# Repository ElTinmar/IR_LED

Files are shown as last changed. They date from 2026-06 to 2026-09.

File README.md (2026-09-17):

# IR_LED

This is an open-source infra-red illumnination solution (LED panel and driver) for machine vision.
An arduino nano every sits at the core of the driver board, and allows remote control from a PC through serial communication

The main features are: 

- infra-red LED panel, with 3 separately addressable concentric rings  
- manual or remote control of the brightness for the 3 channels
- LED driver can be strobed with the open-collector trigger output of a machine vision camera,
which significantly reduces heat output
- the temperature of the LED panel is measured in real time and can by controlled with a fan. 
The fan PWM can be set manually or via a software PID controller on the arduino

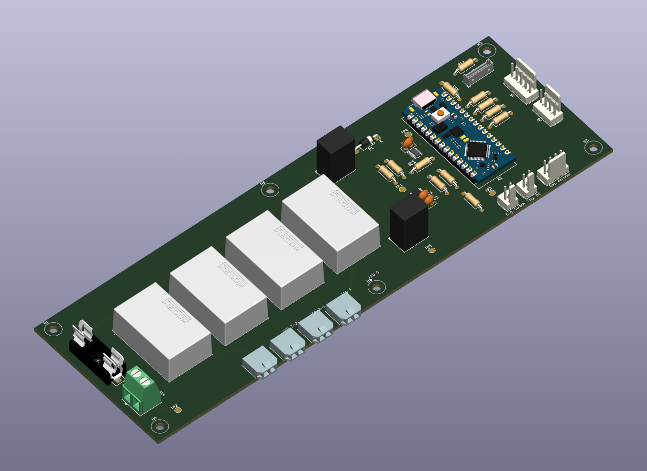
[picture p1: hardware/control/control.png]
Control Board Schematic


## hardware

PCB design files (Kicad v10)

## firmware

Arduino code (Arduino Nano Every)
 
## software

Python driver and GUI on the PC side

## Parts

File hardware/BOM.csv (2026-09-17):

num boards: | 2
board | Id | Designator | Footprint | Quantity (per board) | Safety margin (+ x%) | Quantity (total) | Designation | Supplier | Ref | Unit price | Price total | Link
rotary_encoder | 1 | H1, H2 | MountingHole_2.2mm_M2 | 2 | 0 | 4 | MountingHole
rotary_encoder | 2 | J1 | Molex_KK-254_AE-6410-04A_1x04_P2.54mm_Vertical | 1 | 100 | 4 | Conn_01x04_Pin | Mouser | 538-22-29-2041 | 0.579 | 2.316 | https://www.mouser.de/en/ProductDetail/Molex/22-29-2041
rotary_encoder | 3 | SW1 | RotaryEncoder_Alps_EC11E-Switch_Vertical_H20mm | 1 | 0 | 2 | RotaryEncoder_Switch | Mouser | 688-EC11E183440C | 6.03 | 12.06 | https://www.mouser.de/en/ProductDetail/Alps-Alpine/EC11E183440C
status_LED | 1 | D1, D2, D3, D4 | LED_D5.0mm | 4 | 0 | 8 | LED | Mouser | 941-C503BABNCW0X0342 | 0.127 | 1.016 | https://www.mouser.de/en/ProductDetail/Cree-LED/C503B-ABN-CW0X0342
status_LED | 2 | H1, H2 | MountingHole_2.2mm_M2 | 2 | 0 | 4 | MountingHole
status_LED | 3 | J1 | Molex_KK-254_AE-6410-05A_1x05_P2.54mm_Vertical | 1 | 0 | 2 | Conn_01x05_Pin | Mouser | 538-22-27-2051 | 0.36 | 0.72 | https://www.mouser.de/en/ProductDetail/Molex/22-27-2051
control | 1 | A1 | Arduino_Nano | 1 | 0 | 2 | Arduino_Nano_Every | Mouser | 782-ABX00033 | 12.81 | 25.62 | https://www.mouser.de/en/ProductDetail/Arduino/ABX00033
control | 2 | C1, C4 | C_Disc_D5.0mm_W2.5mm_P2.50mm | 2 | 0 | 4 | 0.1uF | Mouser | 75-1C10X7R104K100B | 0.198 | 0.792 | https://www.mouser.de/en/ProductDetail/Vishay-Sprague/1C10X7R104K100B
control | 3 | C2 | C_Disc_D5.0mm_W2.5mm_P2.50mm | 1 | 0 | 2 | 10uF | Mouser | RCER71E106K3DBH03A | 0.476 | 0.952 | https://www.mouser.de/en/ProductDetail/Murata-Electronics/RCER71E106K3DBH03A
control | 4 | D1 | D_DO-41_SOD81_P10.16mm_Horizontal | 1 | 0 | 2 | 1N5817 | Mouser | 625-1N5817-E3/73 | 0.132 | 0.264 | https://www.mouser.de/en/ProductDetail/Vishay-Semiconductors/1N5817-E3-73
control | 5 | F1 | FUSE_646_1_LTF | 1 | 0 | 2 | 64600001003 | Mouser | 576-64600001003 | 0.903 | 1.806 | https://www.mouser.de/en/ProductDetail/Littelfuse/64600001003
control | 6 | H1, H2, H3, H4, H5, H6 | MountingHole_3.2mm_M3 | 6 | 0 | 12 | MountingHole
control | 7 | IC1 | SOP50P326X110-16N | 1 | 100 | 4 | TMUX4053DYYR | Mouser | 595-TMUX4053DYYR | 0.356 | 1.424 | https://www.mouser.de/en/ProductDetail/Texas-Instruments/TMUX4053DYYR
control | 8 | J1, J2, J3, J4 | Molex_Micro-Fit_3.0_43650-0200_1x02_P3.00mm_Horizontal | 4 | 100 | 16 | Conn_01x02_Pin | Mouser | 538-43650-0200 | 0.785 | 12.56 | https://www.mouser.de/en/ProductDetail/Molex/43650-0200
control | 9 | J5 | Molex_KK-254_AE-6410-05A_1x05_P2.54mm_Vertical | 1 | 100 | 4 | Conn_01x05_Pin | Mouser | 538-22-27-2051 | 0.36 | 1.44 | https://www.mouser.de/en/ProductDetail/Molex/22-27-2051
control | 10 | J6, J11 | Molex_KK-254_AE-6410-04A_1x04_P2.54mm_Vertical | 2 | 100 | 8 | Conn_01x04_Pin | Mouser | 538-22-29-2041 | 0.579 | 4.632 | https://www.mouser.de/en/ProductDetail/Molex/22-29-2041
control | 11 | J7 | Molex_PicoBlade_53047-0810_1x08_P1.25mm_Vertical | 1 | 100 | 4 | Conn_01x08_Pin | Mouser | 538-53047-0810 | 0.361 | 1.444 | https://www.mouser.de/en/ProductDetail/Molex/53047-0810
control | 12 | J8, J12 | Molex_KK-254_AE-6410-02A_1x02_P2.54mm_Vertical | 2 | 100 | 8 | Conn_01x02_Pin | Mouser | 538-22-29-2021 | 0.376 | 3.008 | https://www.mouser.de/en/ProductDetail/Molex/22-29-2021
control | 13 | J9 | TerminalBlock_Phoenix_MKDS-1,5-2-5.08_1x02_P5.08mm_Horizontal | 1 | 0 | 2 | Screw_Terminal_01x02 | Mouser | 651-1985904 | 1.01 | 2.02 | https://www.mouser.de/en/ProductDetail/Phoenix-Contact/1985904
control | 14 | PS1, PS2, PS3, PS4 | CONV_CRED-48-1.05 | 4 | 0 | 8 | RCDE-48-1.05 | Mouser | 919-RCDE-48-1.05 | 7.43 | 59.44 | https://www.mouser.de/en/ProductDetail/RECOM-Power/RCDE-48-1.05
control | 15 | R1, R2, R3, R10, R11, R12 | R_Axial_DIN0207_L6.3mm_D2.5mm_P10.16mm_Horizontal | 6 | 0 | 12 | 10k
control | 16 | R4, R5 | R_Axial_DIN0207_L6.3mm_D2.5mm_P10.16mm_Horizontal | 2 | 0 | 4 | 4.7k
control | 17 | R6, R7, R8, R9 | R_Axial_DIN0207_L6.3mm_D2.5mm_P10.16mm_Horizontal | 4 | 0 | 8 | 220
control | 18 | TP1, TP2, TP3, TP4, TP5, TP6 | TestPoint_Pad_D2.0mm | 6 | 0 | 12 | TestPoint
control | 19 | U2 | MSOP-10_3x3mm_P0.5mm | 1 | 0 | 2 | MCP4728 | Mouser | 579-MCP4728-E/UN | 2.15 | 4.3 | https://www.mouser.de/en/ProductDetail/Microchip-Technology/MCP4728-E-UN
control | 20 | U4 | Converter_DCDC_RECOM_R-78HB-0.5_THT | 1 | 0 | 2 | R-78HB12-0.5 | Mouser | 919-R-78HB12-0.5 | 14.67 | 29.34 | https://www.mouser.de/en/ProductDetail/RECOM-Power/R-78HB12-0.5
control | 21 | U5 | Converter_DCDC_RECOM_R-78HB-0.5_THT | 1 | 0 | 2 | R-78HB5.0-0.5 | Mouser | 919-R-78HB5.0-0.5 | 13.67 | 27.34 | https://www.mouser.de/en/ProductDetail/RECOM-Power/R-78HB5.0-0.5
LED_panel | 1 | C1 | C_0805_2012Metric | 1 | 0 | 2 | 0.1uF | Mouser | 81-GCJ21BR71E104KA1L | 0.361 | 0.722 | https://www.mouser.de/en/ProductDetail/Murata-Electronics/GCJ21BR71E104KA01L
LED_panel | 2 | H1, H2, H3, H4, H5, H6 | MountingHole_3.2mm_M3 | 6 | 0 | 12 | MountingHole
LED_panel | 3 | IC1 | SOT65P210X110-6N | 1 | 100 | 4 | TMP126NDCKR | Mouser | 595-TMP126NDCKR | 1.12 | 4.48 | https://www.mouser.de/en/ProductDetail/Texas-Instruments/TMP126NDCKR
LED_panel | 4 | J0, J1, J2-1, J2-2 | Molex_Micro-Fit_3.0_43650-0224_1x02-1MP_P3.00mm_Vertical | 4 | 100 | 16 | Conn_01x02_Pin | Mouser | 538-43650-0224 | 2.05 | 32.8 | https://www.mouser.de/en/ProductDetail/Molex/43650-0224
LED_panel | 5 | J2 | Molex_PicoBlade_53261-0871_1x08-1MP_P1.25mm_Horizontal | 1 | 100 | 4 | Conn_01x08_Pin | Mouser | 538-53261-0871 | 0.869 | 3.476 | https://www.mouser.de/en/ProductDetail/Molex/53261-0871
LED_panel | 6 | LED1, LED2, LED3, LED4, LED5, LED6, LED7, LED8, LED9, LED10, LED11, LED12, LED13, LED14, LED15, LED16, LED17, LED18, LED19, LED20, LED21, LED22, LED23, LED24, LED25, LED26, LED27, LED28, LED29, LED30, LED31, LED32, LED33, LED34, LED35, LED36 | SFH4725ASA01 | 36 | 25 | 90 | SFH_4725AS_A01 | Mouser | 720-SFH4725ASAA0273 | 2.47 | 222.3 | https://www.mouser.de/en/ProductDetail/ams-OSRAM/SFH-4725AS-A01
 |  |  |  |  |  | 0
cables |  |  |  |  |  | 0
Control : LED_panel | 1 |  |  | 1 | 0 | 2 | PicoBlade 8 positions female/female | Mouser | 538-15134-0801 | 5.99 | 11.98 | https://www.mouser.de/en/ProductDetail/Molex/15134-0801
Control : LED_panel | 2 |  |  | 4 | 0 | 8 | MicroFit3.0 2 positions female/female | Mouser | 538-214750-1021 | 2.19 | 17.52 | https://www.mouser.de/en/ProductDetail/Molex/214750-1021
Control : rotary_encoder | 1 |  |  | 1 | 0 | 2 | KK 4 positions female/female | Mouser | 538-217796-1042 | 3.08 | 6.16 | https://www.mouser.de/en/ProductDetail/Molex/217796-1042
Control : switch | 1 |  |  | 1 | 0 | 2 | KK 2 positions female/pigtail | Mouser | 538-217797-1023 | 1.94 | 3.88 | https://www.mouser.de/en/ProductDetail/Molex/217797-1023
Control : camera | 1 |  |  | 1 | 0 | 2 | KK 2 positions female/pigtail | Mouser | 538-217797-1023 | 1.94 | 3.88 | https://www.mouser.de/en/ProductDetail/Molex/217797-1023
Control : status_LED | 1 |  |  | 1 | 0 | 2 | KK 5 positions female/female | Mouser | 538-217796-1052 | 2.67 | 5.34 | https://www.mouser.de/en/ProductDetail/Molex/217796-1052
other components
switch | 1 |  |  | 1 | 0 | 2 | SPST cam trigger switch PM | Mouser | 633-MN11S2A1W01 | 5.19 | 10.38 | https://www.mouser.de/en/ProductDetail/NKK-Switches/MN11S2A1W01
PSU | 2 |  |  | 1 | 0 | 2 | MeanWell | Digikey | 1866-2274-ND | 90.7 | 181.4 | https://www.digikey.de/de/products/detail/mean-well-usa-inc/HEP-240-48A/7703829
extra
solder paste |  |  |  |  |  | 1 | Lead free, Sn96.5/Ag03/Cu0.5 | Mouser | 910-SMD291SNL10T5 | 32.01 | 32.01 | https://www.mouser.de/en/ProductDetail/Chip-Quik/SMD291SNL10T5
fuses |  |  |  |  |  | 10 | MeanWell HEP-240-48 | Mouser | 576-0235006.MXP | 0.466 | 4.66 | https://www.mouser.de/en/ProductDetail/Littelfuse/0235006.MXP

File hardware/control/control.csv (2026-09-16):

Id | Designator | Footprint | Quantity | Designation | Supplier and ref
1 | A1 | Arduino_Nano | 1 | Arduino_Nano_Every
2 | C1, C4 | C_Disc_D5.0mm_W2.5mm_P2.50mm | 2 | 0.1uF
3 | C2 | C_Disc_D5.0mm_W2.5mm_P2.50mm | 1 | 10uF
4 | D1 | D_DO-41_SOD81_P10.16mm_Horizontal | 1 | 1N5817
5 | F1 | FUSE_646_1_LTF | 1 | 64600001003
6 | H1, H2, H3, H4, H5, H6 | MountingHole_3.2mm_M3 | 6 | MountingHole
7 | IC1 | SOP50P326X110-16N | 1 | TMUX4053DYYR
8 | J1, J2, J3, J4 | Molex_Micro-Fit_3.0_43650-0200_1x02_P3.00mm_Horizontal | 4 | Conn_01x02_Pin
9 | J5 | Molex_KK-254_AE-6410-05A_1x05_P2.54mm_Vertical | 1 | Conn_01x05_Pin
10 | J6, J11 | Molex_KK-254_AE-6410-04A_1x04_P2.54mm_Vertical | 2 | Conn_01x04_Pin
11 | J7 | Molex_PicoBlade_53047-0810_1x08_P1.25mm_Vertical | 1 | Conn_01x08_Pin
12 | J8, J12 | Molex_KK-254_AE-6410-02A_1x02_P2.54mm_Vertical | 2 | Camera Isolated triggers (open collector)
13 | J9 | TerminalBlock_Phoenix_MKDS-1,5-2-5.08_1x02_P5.08mm_Horizontal | 1 | Screw_Terminal_01x02
14 | PS1, PS2, PS3, PS4 | CONV_RCDE-48-1.05 | 4 | RCDE-48-1.05
15 | R1, R2, R3, R10, R11, R12 | R_Axial_DIN0207_L6.3mm_D2.5mm_P10.16mm_Horizontal | 6 | 10k
16 | R4, R5 | R_Axial_DIN0207_L6.3mm_D2.5mm_P10.16mm_Horizontal | 2 | 4.7k
17 | R6, R7, R8, R9 | R_Axial_DIN0207_L6.3mm_D2.5mm_P10.16mm_Horizontal | 4 | 220
18 | TP1, TP2, TP3, TP4, TP5, TP6 | TestPoint_Pad_D2.0mm | 6 | TestPoint
19 | U2 | MSOP-10_3x3mm_P0.5mm | 1 | MCP4728
20 | U4 | Converter_DCDC_RECOM_R-78HB-0.5_THT | 1 | R-78HB12-0.5
21 | U5 | Converter_DCDC_RECOM_R-78HB-0.5_THT | 1 | R-78HB5.0-0.5

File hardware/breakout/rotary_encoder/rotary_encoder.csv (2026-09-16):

Id | Designator | Footprint | Quantity | Designation | Supplier and ref
1 | H1, H2 | MountingHole_2.2mm_M2 | 2 | MountingHole
2 | J1 | Molex_KK-254_AE-6410-04A_1x04_P2.54mm_Vertical | 1 | Conn_01x04_Pin
3 | SW1 | RotaryEncoder_Alps_EC11E-Switch_Vertical_H20mm | 1 | RotaryEncoder_Switch

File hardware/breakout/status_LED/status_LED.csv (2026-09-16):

Id | Designator | Footprint | Quantity | Designation | Supplier and ref
1 | D1, D2, D3, D4 | LED_D5.0mm | 4 | LED
2 | H1, H2 | MountingHole_2.2mm_M2 | 2 | MountingHole
3 | J1 | Molex_KK-254_AE-6410-05A_1x05_P2.54mm_Vertical | 1 | Conn_01x05_Pin

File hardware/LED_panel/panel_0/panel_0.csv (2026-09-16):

Id | Designator | Footprint | Quantity | Designation | Supplier and ref
1 | C1 | C_0805_2012Metric | 1 | 0.1uF
2 | H1, H2, H3, H4, H5, H6 | MountingHole_3.2mm_M3 | 6 | MountingHole
3 | IC1 | SOT65P210X110-6N | 1 | TMP126NDCKR
4 | J0, J1, J2-1, J2-2 | Molex_Micro-Fit_3.0_43650-0224_1x02-1MP_P3.00mm_Vertical | 4 | Conn_01x02_Pin
5 | J2 | Molex_PicoBlade_53261-0871_1x08-1MP_P1.25mm_Horizontal | 1 | Conn_01x08_Pin
6 | LED1, LED2, LED3, LED4, LED5, LED6, LED7, LED8, LED9, LED10, LED11, LED12, LED13, LED14, LED15, LED16, LED17, LED18, LED19, LED20, LED21, LED22, LED23, LED24, LED25, LED26, LED27, LED28, LED29, LED30, LED31, LED32, LED33, LED34, LED35, LED36 | SFH4725ASA01 | 36 | SFH_4725AS_A01

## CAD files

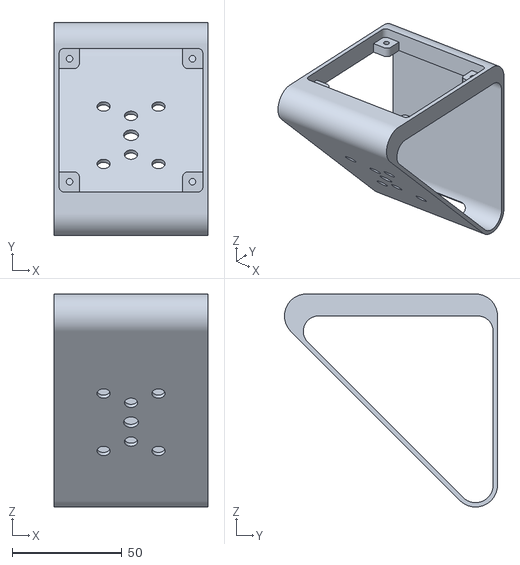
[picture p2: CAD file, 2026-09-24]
hardware/breakout/breakout-base.stl
70.0 x 97.0 x 97.0

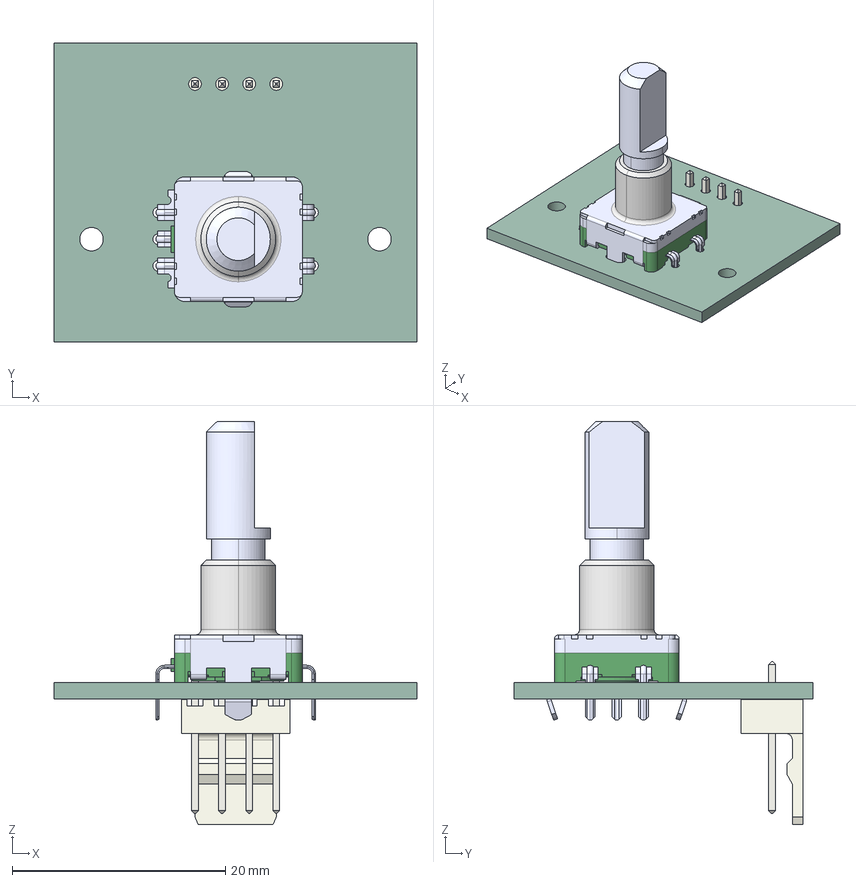
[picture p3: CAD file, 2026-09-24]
hardware/breakout/rotary_encoder/rotary_encoder.step
34.0 x 28.0 x 37.8 mm
EC11E183440C
Molex_AE_6410_04A
rotary_encoder-unsaved-export-sQqqTO_PCB

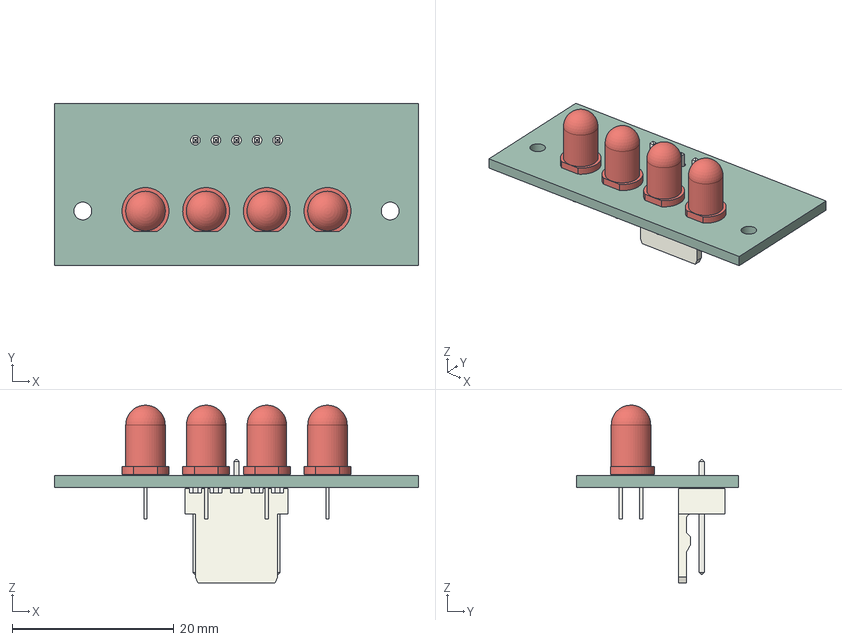
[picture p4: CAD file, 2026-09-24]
hardware/breakout/status_LED/status_LED.step
45.0 x 20.0 x 22.0 mm
LED_D5.0mm x 4
Molex_AE_6410_05A
status_LED-unsaved-export-cohGWM_PCB

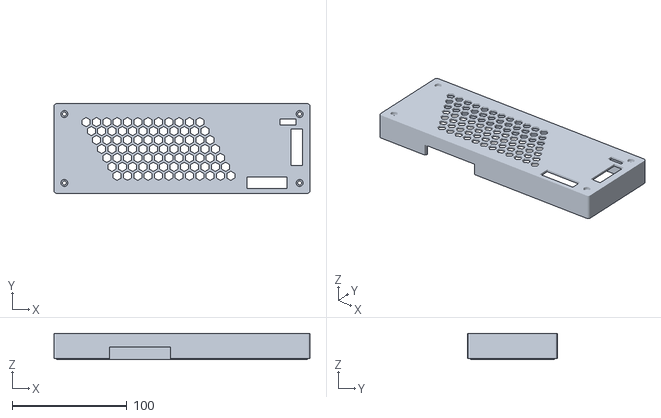
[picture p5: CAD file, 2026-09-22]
hardware/control/control-lid.stl
223.0 x 78.0 x 23.0

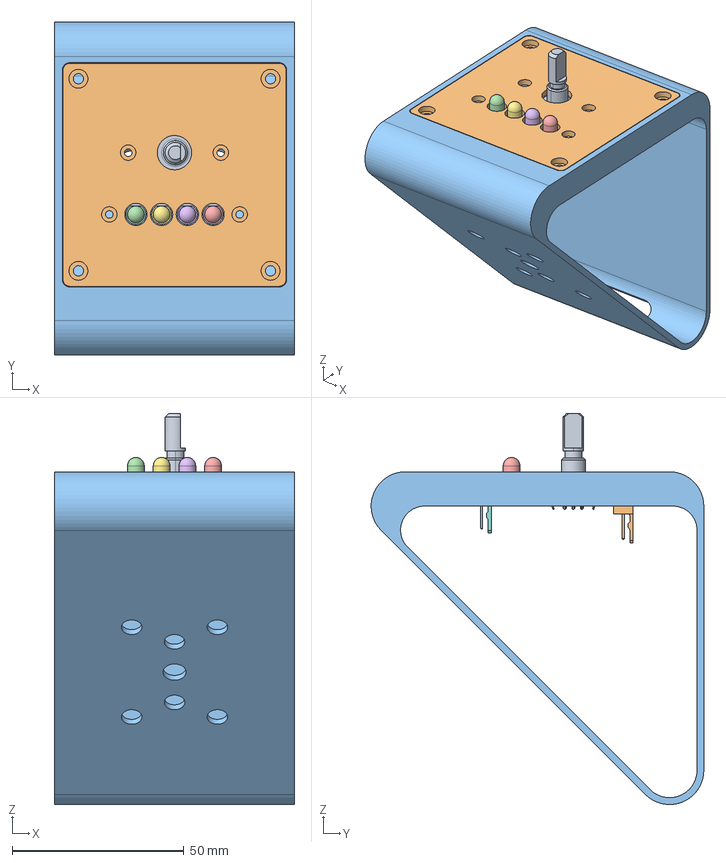
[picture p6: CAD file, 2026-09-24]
hardware/breakout/breakout.FCStd
70.0 x 97.0 x 114.0 mm
EC11E183440C
Molex_AE_6410_04A
rotary_encoder-unsaved-export-sQqqTO_PCB
LED_D5.0mm
LED_D5.0mm002
LED_D5.0mm004
LED_D5.0mm006
Molex_AE_6410_05A
status_LED-unsaved-export-cohGWM_PCB
panel
base

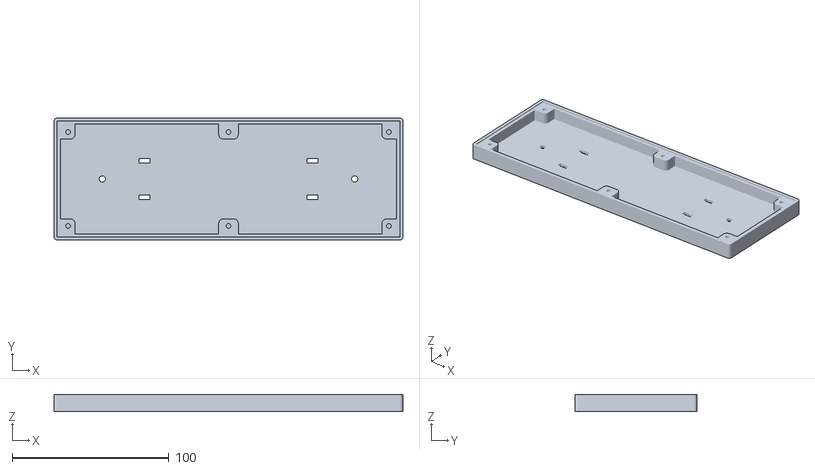
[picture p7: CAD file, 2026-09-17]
hardware/control/control-base.stl
223.0 x 78.0 x 11.0

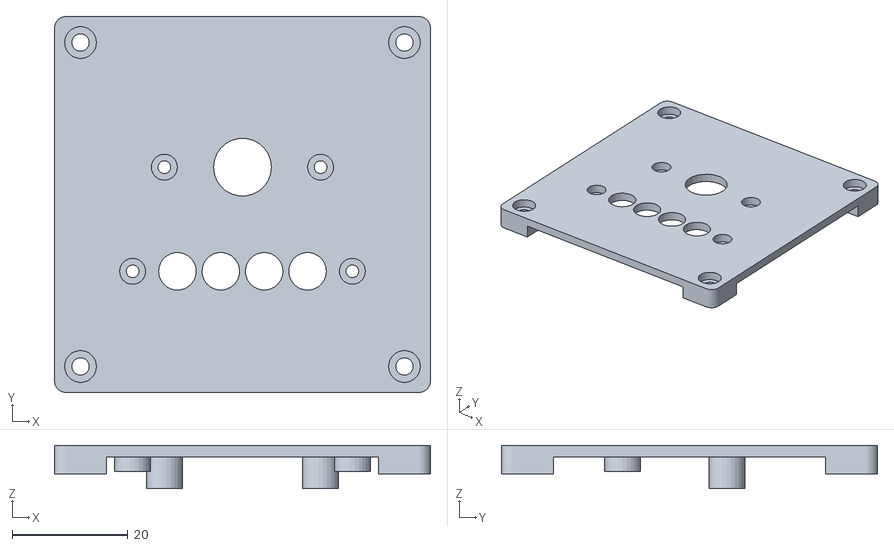
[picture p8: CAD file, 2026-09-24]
hardware/breakout/breakout-panel.stl
65.0 x 65.0 x 7.50

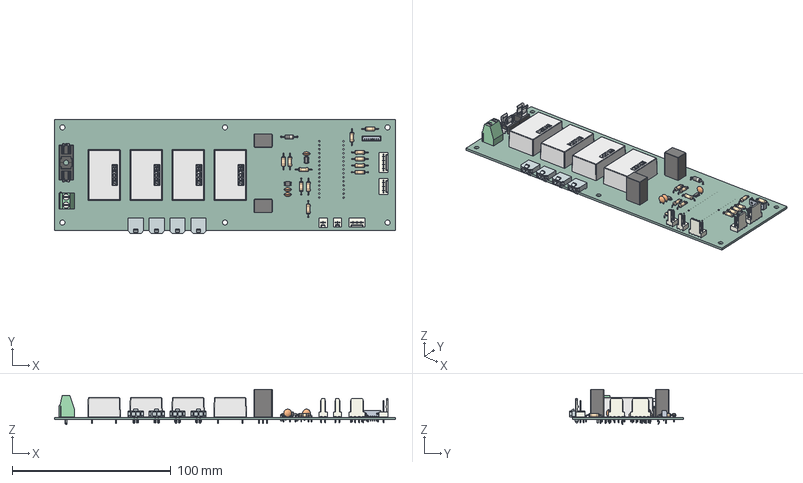
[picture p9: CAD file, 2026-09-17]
hardware/control/control.step
215.0 x 71.9 x 22.3 mm
R_Axial_DIN0207_L63mm_D25mm_P1016mm_Horizontal x 12
436500200wbm000_01 x 4
RCDE-48_pinning x 8
RCDE-48_baseplate x 8
RCDE-48_case x 8
Molex_AE_6410_05A
Molex_AE_6410_02A x 2
Converter_DCDC_RECOM_R-78HB-0.5_THT x 2
BODY-TSSOP x 2
LEAD-TSSOP x 32
C_Disc_D50mm_W25mm_P250mm x 3
MSOP-10_3x3mm_P0.5mm
Molex_AE_6410_04A x 2
T6982
T688800
T6982_MIR1
T688800_MIR1
TerminalBlock_Phoenix_MKDS-1,5-2-5.08_1x02_P5.08mm_Horizontal
D_DO-41_SOD81_P10.16mm_Horizontal
control-unsaved-export-1D0PUn_PCB

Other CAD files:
hardware/control/control.FCStd

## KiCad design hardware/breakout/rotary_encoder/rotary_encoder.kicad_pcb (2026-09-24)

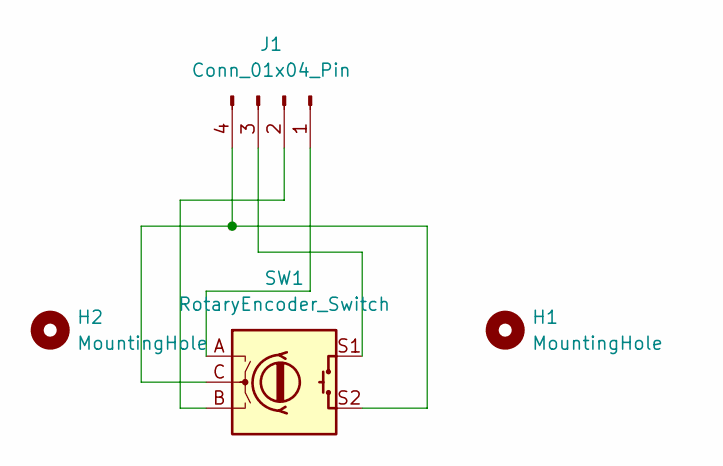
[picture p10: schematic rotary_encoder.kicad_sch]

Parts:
H1, H2: MountingHole; MountingHole_2.2mm_M2
J1: Conn_01x04_Pin; Molex_KK-254_AE-6410-04A_1x04_P2.54mm_Vertical
SW1: RotaryEncoder_Switch; RotaryEncoder_Alps_EC11E-Switch_Vertical_H20mm

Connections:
unnamed: J1.1, SW1.A
unnamed: J1.2, SW1.B
unnamed: J1.3, SW1.S1
unnamed: J1.4, SW1.C, SW1.S2

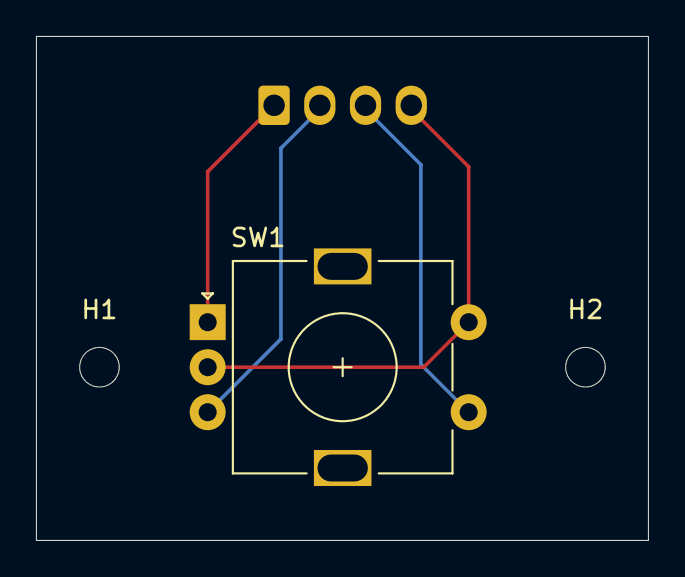
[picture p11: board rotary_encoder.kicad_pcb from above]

Board: 2 copper layers, 34.0 x 28.0 mm, 4 parts (1 on the bottom side), 4 nets.

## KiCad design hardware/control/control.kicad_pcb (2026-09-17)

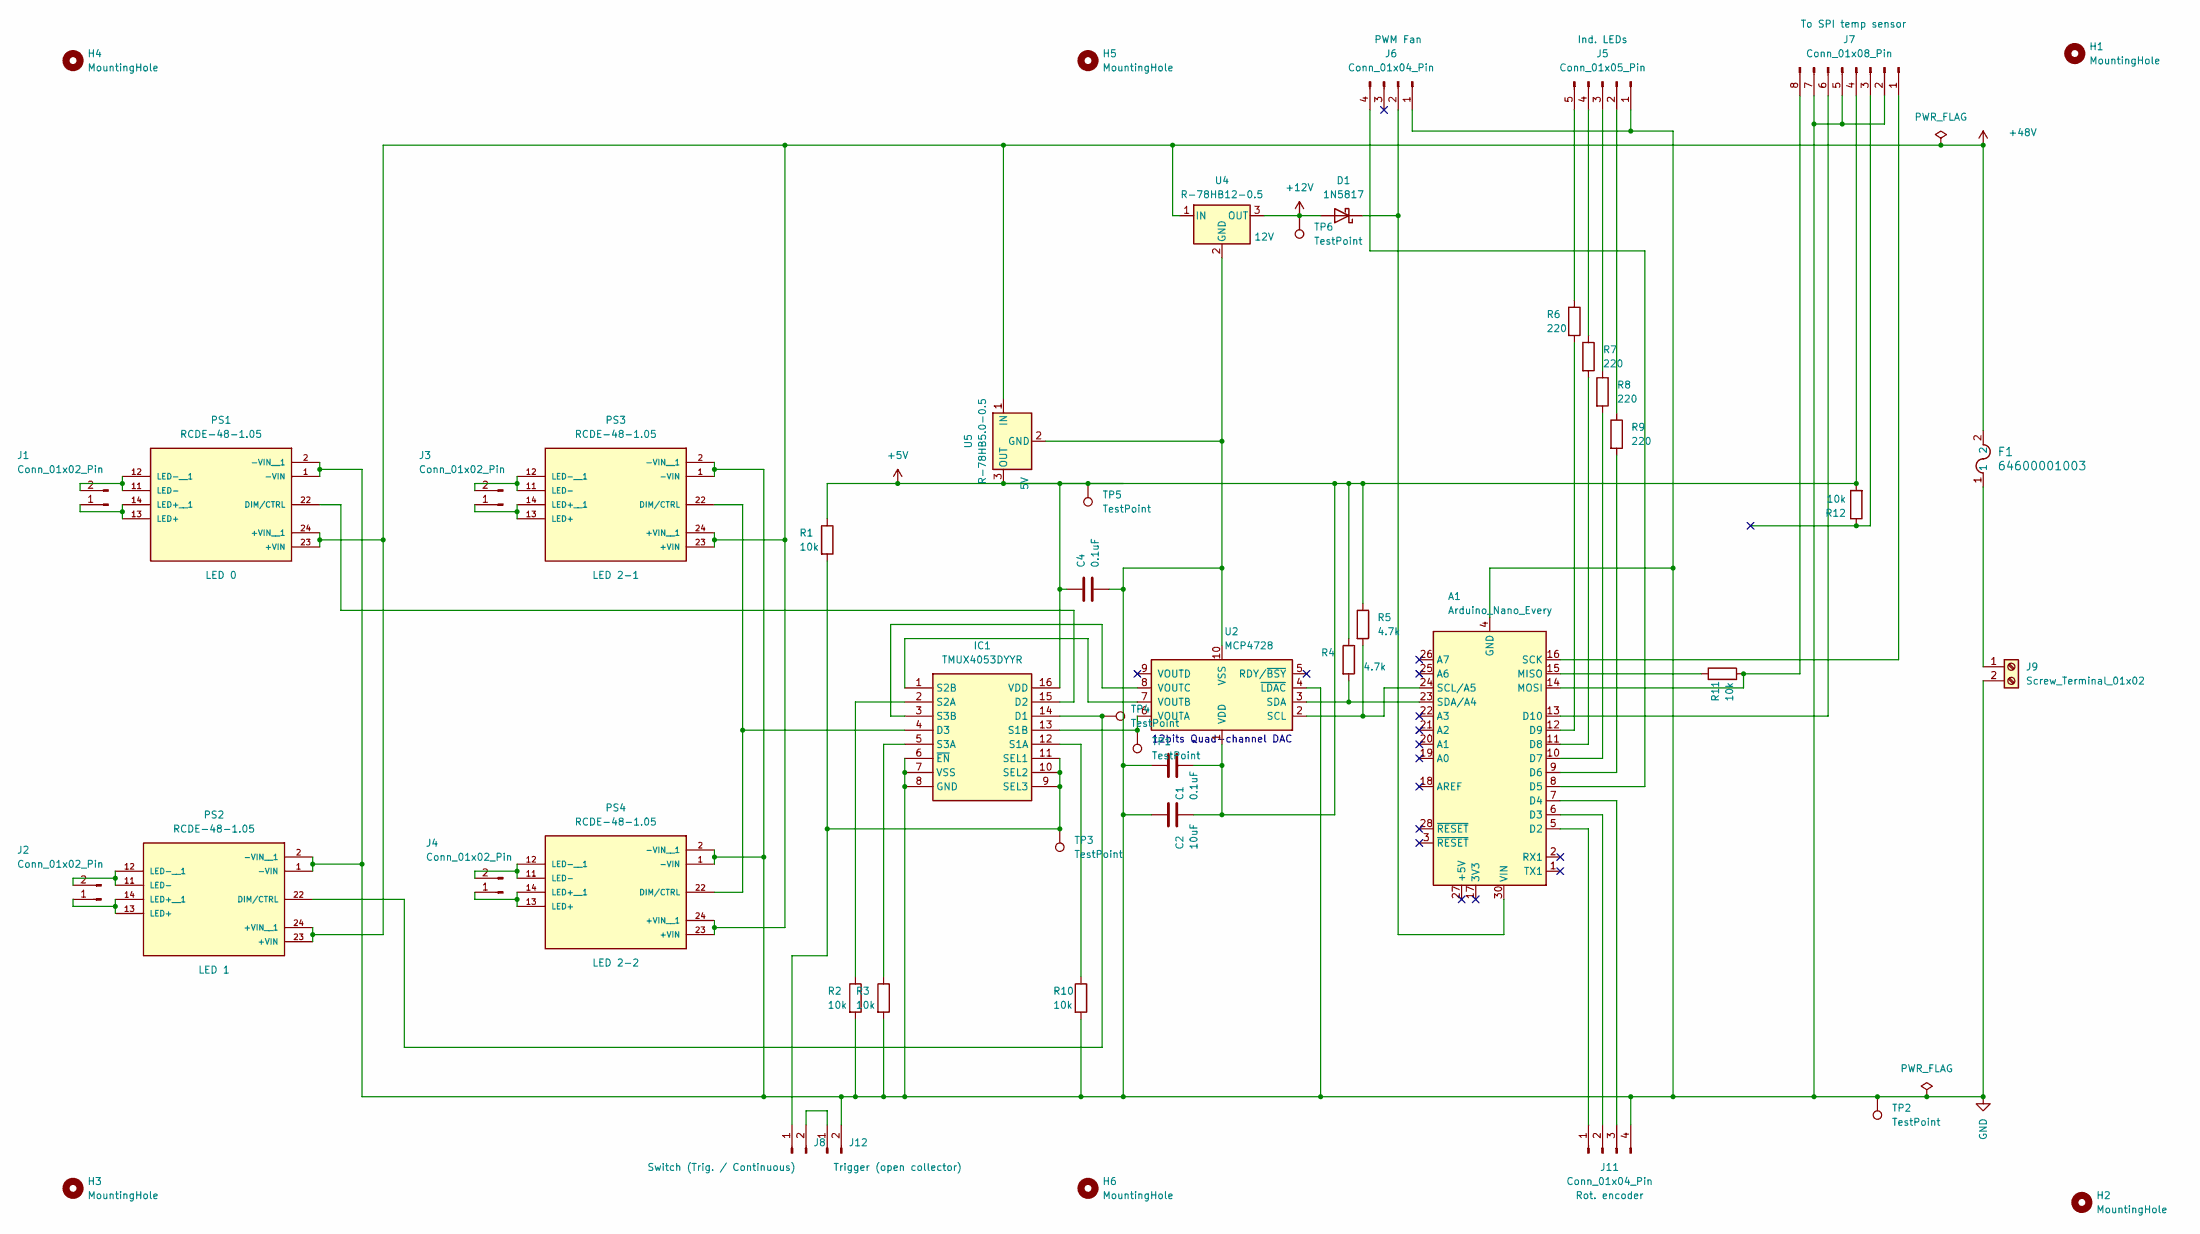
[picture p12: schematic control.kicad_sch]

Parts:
A1: Arduino_Nano_Every; Arduino_Nano
C1, C4: 0.1uF; C_Disc_D5.0mm_W2.5mm_P2.50mm
C2: 10uF; C_Disc_D5.0mm_W2.5mm_P2.50mm
D1: 1N5817; D_DO-41_SOD81_P10.16mm_Horizontal
F1: 64600001003; FUSE_646_1_LTF
H1, H2, H3, H4, H5, H6: MountingHole; MountingHole_3.2mm_M3
IC1: TMUX4053DYYR; SOP50P326X110-16N; Mouser Part Number 595-TMUX4053DYYR
J1, J2, J3, J4: Conn_01x02_Pin; Molex_Micro-Fit_3.0_43650-0200_1x02_P3.00mm_Horizontal
J5: Conn_01x05_Pin; Molex_KK-254_AE-6410-05A_1x05_P2.54mm_Vertical
J6, J11: Conn_01x04_Pin; Molex_KK-254_AE-6410-04A_1x04_P2.54mm_Vertical
J7: Conn_01x08_Pin; Molex_PicoBlade_53047-0810_1x08_P1.25mm_Vertical
J8, J12: Camera Isolated triggers (open collector); Molex_KK-254_AE-6410-02A_1x02_P2.54mm_Vertical
J9: Screw_Terminal_01x02; TerminalBlock_Phoenix_MKDS-1,5-2-5.08_1x02_P5.08mm_Horizont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
PS1, PS2, PS3, PS4: RCDE-48-1.05; CONV_RCDE-48-1.05; PARTREV 0/2019
R1, R2, R3, R10, R11, R12: 10k; R_Axial_DIN0207_L6.3mm_D2.5mm_P10.16mm_Horizontal
R4, R5: 4.7k; R_Axial_DIN0207_L6.3mm_D2.5mm_P10.16mm_Horizontal
R6, R7, R8, R9: 220; R_Axial_DIN0207_L6.3mm_D2.5mm_P10.16mm_Horizontal
TP1, TP2, TP3, TP4, TP5, TP6: TestPoint; TestPoint_Pad_D2.0mm
U2: MCP4728; MSOP-10_3x3mm_P0.5mm
U4: R-78HB12-0.5; Converter_DCDC_RECOM_R-78HB-0.5_THT
U5: R-78HB5.0-0.5; Converter_DCDC_RECOM_R-78HB-0.5_THT

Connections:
+5V: C1.2, C2.2, C4.1, IC1.16 (VDD), J7.4, R1.1, R4.1, R5.1, R12.2, TP5.1 (1_1), U2.1 (VDD), U5.3 (OUT)
+12V: D1.2 (A), TP6.1 (1_1), U4.3 (OUT)
+48V: F1.2, PS1.23 (+VIN), PS1.24 (+VIN__1), PS2.23 (+VIN), PS2.24 (+VIN__1), PS3.23 (+VIN), PS3.24 (+VIN__1), PS4.23 (+VIN), PS4.24 (+VIN__1), U4.1 (IN), U5.1 (IN)
GND: A1.4 (GND), A1.29 (GND), C1.1, C2.1, C4.2, IC1.6 (~EN), IC1.7 (VSS), IC1.8 (GND), J5.1, J6.1, J7.2, J7.5, J7.7, J9.2, J11.4, J12.2, PS1.1 (-VIN), PS1.2 (-VIN__1), PS2.1 (-VIN), PS2.2 (-VIN__1), PS3.1 (-VIN), PS3.2 (-VIN__1), PS4.1 (-VIN), PS4.2 (-VIN__1), R2.2, R3.2, R10.2, TP2.1 (1_1), U2.4 (~LDAC), U2.10 (VSS), U4.2 (GND), U5.2 (GND)
unnamed: A1.5 (D2), J11.1
unnamed: A1.6 (D3), J11.2
unnamed: A1.7 (D4), J11.3
unnamed: A1.8 (D5), J6.4
unnamed: A1.9 (D6), R9.2
unnamed: A1.10 (D7), R8.2
unnamed: A1.11 (D8), R7.2
unnamed: A1.12 (D9), R6.2
unnamed: A1.13 (D10), J7.6
unnamed: A1.15 (MISO), R11.1
unnamed: A1.14 (MOSI), J7.8, R11.2
unnamed: A1.16 (SCK), J7.1
unnamed: A1.24 (SCL/A5), R5.2, U2.2 (SCL)
unnamed: A1.23 (SDA/A4), R4.2, U2.3 (SDA)
unnamed: A1.30 (VIN), D1.1 (K), J6.2
unnamed: IC1.14 (D1), PS2.22 (DIM/CTRL), TP4.1 (1_1)
unnamed: IC1.15 (D2), PS1.22 (DIM/CTRL)
unnamed: IC1.4 (D3), PS3.22 (DIM/CTRL), PS4.22 (DIM/CTRL)
unnamed: IC1.12 (S1A), R10.1
unnamed: IC1.13 (S1B), TP1.1 (1_1), U2.6 (VOUTA)
unnamed: IC1.2 (S2A), R2.1
unnamed: IC1.1 (S2B), U2.7 (VOUTB)
unnamed: IC1.5 (S3A), R3.1
unnamed: IC1.3 (S3B), U2.8 (VOUTC)
unnamed: IC1.9 (SEL3), IC1.10 (SEL2), IC1.11 (SEL1), J8.1, R1.2, TP3.1 (1_1)
unnamed: J1.1, PS1.13 (LED+), PS1.14 (LED+__1)
unnamed: J1.2, PS1.11 (LED-), PS1.12 (LED-__1)
unnamed: J2.1, PS2.13 (LED+), PS2.14 (LED+__1)
unnamed: J2.2, PS2.11 (LED-), PS2.12 (LED-__1)
unnamed: J3.1, PS3.13 (LED+), PS3.14 (LED+__1)
unnamed: J3.2, PS3.11 (LED-), PS3.12 (LED-__1)
unnamed: J4.1, PS4.13 (LED+), PS4.14 (LED+__1)
unnamed: J4.2, PS4.11 (LED-), PS4.12 (LED-__1)
unnamed: J5.2, R9.1
unnamed: J5.3, R8.1
unnamed: J5.4, R7.1
unnamed: J5.5, R6.1
unnamed: F1.1, J9.1
unnamed: J8.2, J12.1

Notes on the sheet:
12bits Quad-channel DAC

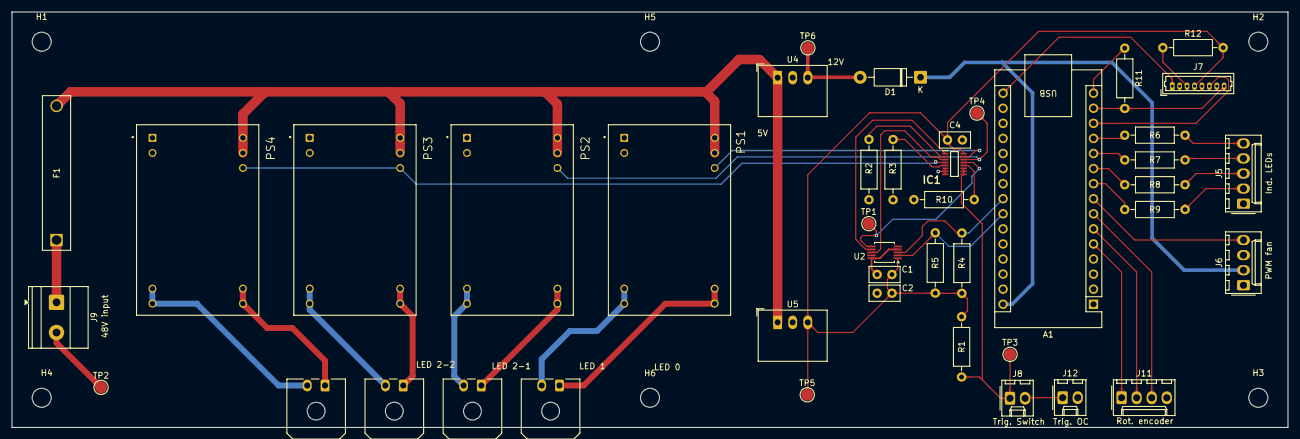
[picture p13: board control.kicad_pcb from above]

Board: 2 copper layers, 215.0 x 70.0 mm, 49 parts (0 on the bottom side), 43 nets.

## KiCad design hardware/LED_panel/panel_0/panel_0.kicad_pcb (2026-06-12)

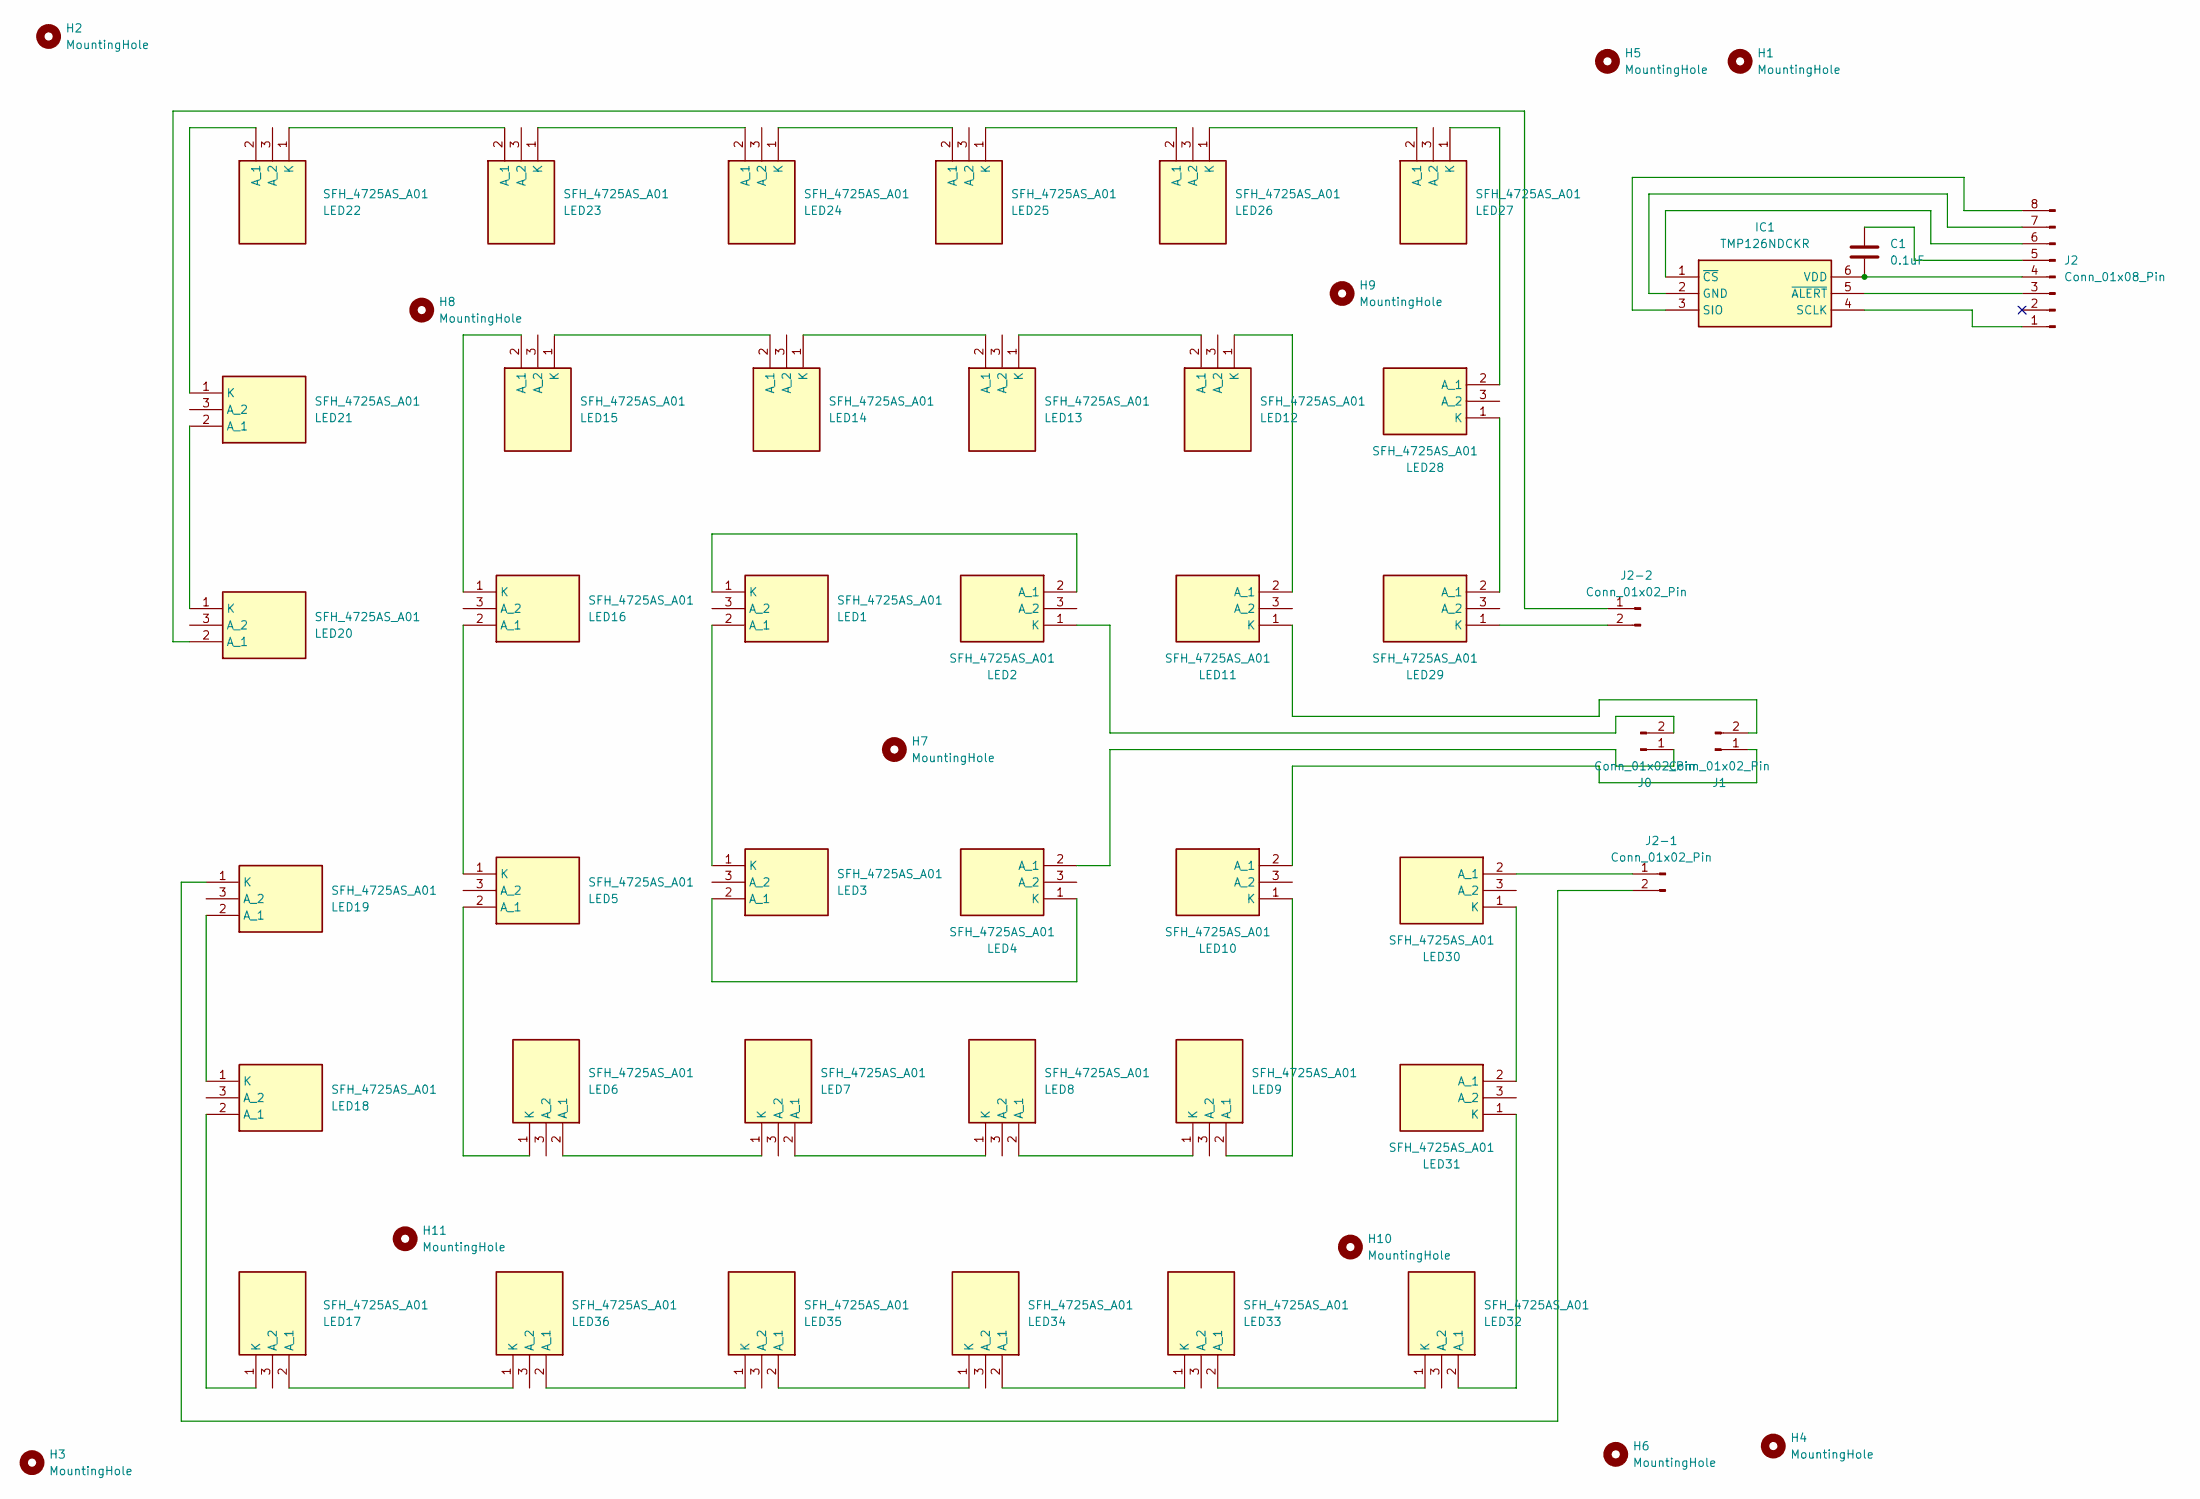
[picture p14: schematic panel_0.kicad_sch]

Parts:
C1: 0.1uF; C_0805_2012Metric
H1, H2, H3, H4, H5, H6: MountingHole; MountingHole_3.2mm_M3
H7, H8, H9, H10, H11: MountingHole; MountingHole_2.2mm_M2
IC1: TMP126NDCKR; SOT65P210X110-6N; Mouser Part Number 595-TMP126NDCKR
J0, J1, J2-1, J2-2: Conn_01x02_Pin; Molex_Micro-Fit_3.0_43650-0224_1x02-1MP_P3.00mm_Vertical
J2: Conn_01x08_Pin; Molex_PicoBlade_53261-0871_1x08-1MP_P1.25mm_Horizontal
LED1, LED2, LED3, LED4, LED5, LED6, LED7, LED8, LED9, LED10, LED11, LED12, LED13, LED14, LED15, LED16, LED17, LED18, LED19, LED20, LED21, LED22, LED23, LED24, LED25, LED26, LED27, LED28, LED29, LED30, LED31, LED32, LED33, LED34, LED35, LED36: SFH_4725AS_A01; SFH4725ASA01; Manufacturer_Part_Number SFH 4725AS A01

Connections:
unnamed: IC1.2 (GND), J2.7
unnamed: IC1.4 (SCLK), J2.1
unnamed: IC1.3 (SIO), J2.8
unnamed: C1.2, IC1.6 (VDD), J2.4
unnamed: IC1.5 (~ALERT), J2.3
unnamed: IC1.1 (~CS), J2.6
unnamed: J0.1, LED4.2 (A_1)
unnamed: J0.2, LED2.1 (K)
unnamed: J1.1, LED10.2 (A_1)
unnamed: J1.2, LED11.1 (K)
unnamed: J2-1.1, LED30.2 (A_1)
unnamed: J2-1.2, LED19.1 (K)
unnamed: J2-2.1, LED20.2 (A_1)
unnamed: J2-2.2, LED29.1 (K)
unnamed: C1.1, J2.5
unnamed: LED1.2 (A_1), LED3.1 (K)
unnamed: LED1.1 (K), LED2.2 (A_1)
unnamed: LED3.2 (A_1), LED4.1 (K)
unnamed: LED5.2 (A_1), LED6.1 (K)
unnamed: LED6.2 (A_1), LED7.1 (K)
unnamed: LED7.2 (A_1), LED8.1 (K)
unnamed: LED8.2 (A_1), LED9.1 (K)
unnamed: LED9.2 (A_1), LED10.1 (K)
unnamed: LED11.2 (A_1), LED12.1 (K)
unnamed: LED12.2 (A_1), LED13.1 (K)
unnamed: LED13.2 (A_1), LED14.1 (K)
unnamed: LED14.2 (A_1), LED15.1 (K)
unnamed: LED15.2 (A_1), LED16.1 (K)
unnamed: LED5.1 (K), LED16.2 (A_1)
unnamed: LED17.2 (A_1), LED36.1 (K)
unnamed: LED17.1 (K), LED18.2 (A_1)
unnamed: LED18.1 (K), LED19.2 (A_1)
unnamed: LED20.1 (K), LED21.2 (A_1)
unnamed: LED21.1 (K), LED22.2 (A_1)
unnamed: LED22.1 (K), LED23.2 (A_1)
unnamed: LED23.1 (K), LED24.2 (A_1)
unnamed: LED24.1 (K), LED25.2 (A_1)
unnamed: LED25.1 (K), LED26.2 (A_1)
unnamed: LED26.1 (K), LED27.2 (A_1)
unnamed: LED27.1 (K), LED28.2 (A_1)
unnamed: LED28.1 (K), LED29.2 (A_1)
unnamed: LED30.1 (K), LED31.2 (A_1)
unnamed: LED31.1 (K), LED32.2 (A_1)
unnamed: LED32.1 (K), LED33.2 (A_1)
unnamed: LED33.1 (K), LED34.2 (A_1)
unnamed: LED34.1 (K), LED35.2 (A_1)
unnamed: LED35.1 (K), LED36.2 (A_1)

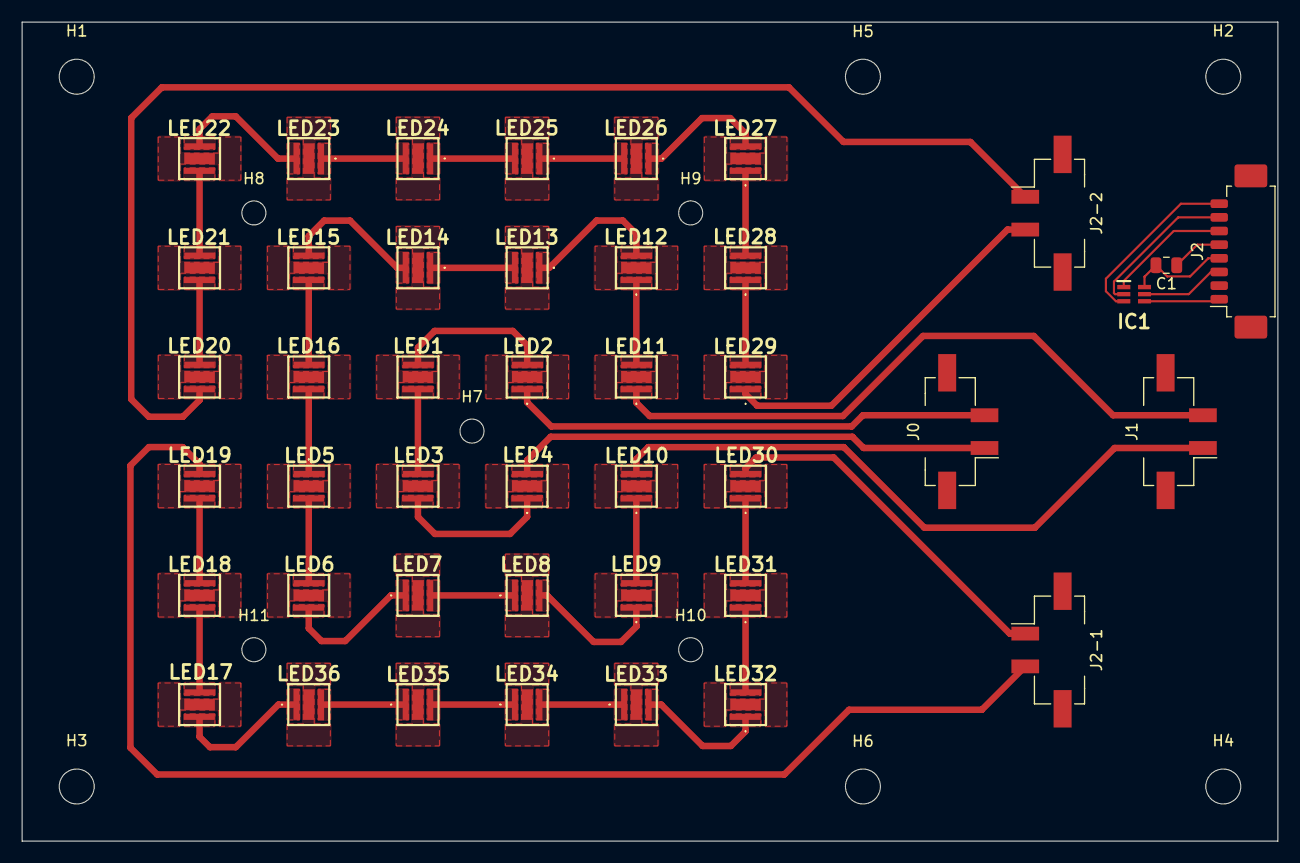
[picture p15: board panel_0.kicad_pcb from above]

Board: 2 copper layers, 115.0 x 75.0 mm, 54 parts (0 on the bottom side), 47 nets.

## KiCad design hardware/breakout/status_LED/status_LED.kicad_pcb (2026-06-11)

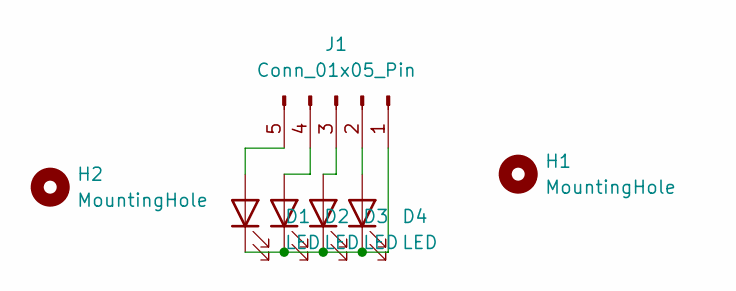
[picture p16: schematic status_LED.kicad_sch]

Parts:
D1, D2, D3, D4: LED; LED_D5.0mm
H1, H2: MountingHole; MountingHole_2.2mm_M2
J1: Conn_01x05_Pin; Molex_KK-254_AE-6410-05A_1x05_P2.54mm_Vertical

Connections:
unnamed: D1.2 (A), J1.5
unnamed: D1.1 (K), D2.1 (K), D3.1 (K), D4.1 (K), J1.1
unnamed: D2.2 (A), J1.4
unnamed: D3.2 (A), J1.3
unnamed: D4.2 (A), J1.2

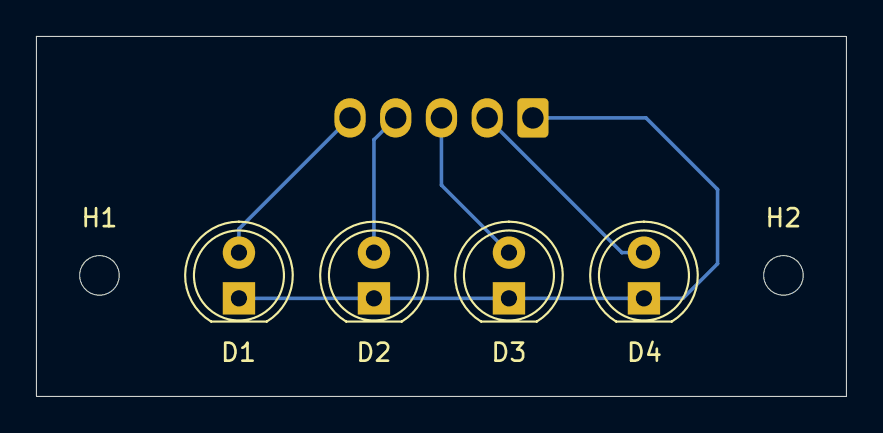
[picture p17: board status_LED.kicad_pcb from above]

Board: 2 copper layers, 45.0 x 20.0 mm, 7 parts (1 on the bottom side), 5 nets.

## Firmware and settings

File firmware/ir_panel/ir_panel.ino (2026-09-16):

#include <Wire.h>
#include <Adafruit_MCP4728.h>
#include <SPI.h>

// ==========================================
// CONFIGURATION FLAGS
// ==========================================
#define DEBUG_MODE 1  // 1 = Debugging (Spammy Serial), 0 = Production (Silent/Clean Protocol)

// --- Identity (used for robust host-side discovery) ---
#define DEVICE_TYPE "LED_PANEL_CONTROLLER"
#define FW_VERSION  "1.1.0"

// --- Pin Definitions ---
const int ENCODER_A = 2;
const int ENCODER_B = 3;
const int ENCODER_SW = 4;
const int FAN_PWM_PIN = 5;

// Status LEDs
const int LED_CH1 = 6;
const int LED_CH2 = 7;
const int LED_CH3 = 8;
const int LED_SATURATION = 9;

// SPI TMP126
const int TMP126_CS = 10;

// ==========================================
// SMART MCP PROXY CLASS (Runtime Fallback)
// ==========================================
class SmartMCP {
private:
  Adafruit_MCP4728 realMcp;
  bool fallbackActive = false;

public:
  bool begin(uint8_t address) {
    pinMode(A4, INPUT_PULLUP);
    pinMode(A5, INPUT_PULLUP);
    delay(5);

    bool busIsOk = (digitalRead(A4) == HIGH && digitalRead(A5) == HIGH);

    if (!busIsOk) {
      Serial.println("WARN: HW_I2C_BUS_DEAD! Falling back to MOCK MCP.");
      fallbackActive = true;
      return true;
    }

    Wire.begin();
    if (!realMcp.begin(address)) {
      Serial.println("WARN: HW_MCP_MISSING! Falling back to MOCK MCP.");
      fallbackActive = true;
      return true;
    }

    Serial.println("SYS: Physical MCP4728 initialized successfully.");
    fallbackActive = false;
    return true;
  }

  bool setChannelValue(MCP4728_channel_t channel, uint16_t value,
                       MCP4728_vref_t vref = MCP4728_VREF_VDD,
                       MCP4728_gain_t gain = MCP4728_GAIN_1X,
                       MCP4728_pd_mode_t pd = MCP4728_PD_MODE_NORMAL) {
    if (fallbackActive) {
      #if DEBUG_MODE
        Serial.print("MOCK: Ch ");
        Serial.print(channel);
        Serial.print(" -> ");
        Serial.println(value);
      #endif
      return true;
    } else {
      return realMcp.setChannelValue(channel, value, vref, gain, pd);
    }
  }

  bool isMockActive() const { return fallbackActive; }
};

SmartMCP mcp;

// --- Global Variables ---
uint16_t dacValues[3] = {2048, 2048, 2048};
int currentChannel = 0;

// Encoder State
int lastStateA;
bool lastButtonReading = HIGH;
bool debouncedButtonState = HIGH;
unsigned long lastDebounceTime = 0;
const unsigned long debounceDelay = 50;

// Serial Parsing Buffer
String inputString = "";

// ==========================================
// TEMPERATURE PID CONTROLLER
// ==========================================
struct PIDController {
  float kp = 8.0f;
  float ki = 0.5f;
  float kd = 2.0f;
  float setpoint = 45.0f;   // degC
  float integral = 0.0f;
  float lastInput = 0.0f;
  bool initialized = false;
  const float outMin = 0.0f;
  const float outMax = 100.0f;   // matches fan duty cycle range
};

PIDController tempPID;
bool pidModeEnabled = false;
bool pidFaultActive = false;
unsigned long lastPidRunTime = 0;
const unsigned long PID_INTERVAL_MS = 1000;   // 1 Hz control loop
uint8_t currentFanDuty = 0;

void init25kHzPWM() {
  TCA0.SPLIT.CTRLA = 0;
  TCA0.SPLIT.CTRLA = TCA_SPLIT_CLKSEL_DIV4_gc | TCA_SPLIT_ENABLE_bm;
  TCA0.SPLIT.CTRLD = TCA_SPLIT_SPLITM_bm;
  TCA0.SPLIT.LPER = 99;
  TCA0.SPLIT.CTRLB &= ~(TCA_SPLIT_LCMP0EN_bm | TCA_SPLIT_LCMP1EN_bm);
  TCA0.SPLIT.CTRLB |= TCA_SPLIT_LCMP2EN_bm;
  TCA0.SPLIT.LCMP2 = 0;
  pinMode(FAN_PWM_PIN, OUTPUT);
}

void setFanDutyCycle(uint8_t duty) {
  if (duty > 100) duty = 100;

  if (duty >= 100) {
    // True 100%: detach WO2 from the pin and drive it statically HIGH.
    // CMP == PER is a degenerate case on TCA split-mode PWM that doesn't
    // reliably produce a full-width pulse (double-buffered CMP/PER/CNT),
    // so we bypass the timer compare channel entirely instead.
    TCA0.SPLIT.CTRLB &= ~TCA_SPLIT_LCMP2EN_bm;
    digitalWrite(FAN_PWM_PIN, HIGH);
  } else if (duty == 0) {
    // Same degenerate-edge concern at the bottom; force it explicitly too.
    TCA0.SPLIT.CTRLB &= ~TCA_SPLIT_LCMP2EN_bm;
    digitalWrite(FAN_PWM_PIN, LOW);
  } else {
    // Normal case: reconnect the timer to the pin and set the duty.
    TCA0.SPLIT.CTRLB |= TCA_SPLIT_LCMP2EN_bm;
    TCA0.SPLIT.LCMP2 = duty;
  }
}

// Reads the ATmega4809 factory-programmed 10-byte unique serial number
String getUniqueID() {
  uint8_t *sernum = (uint8_t*)&SIGROW.SERNUM0;
  char buf[21];
  for (int i = 0; i < 10; i++) {
    sprintf(buf + i * 2, "%02X", sernum[i]);
  }
  buf[20] = '\0';
  return String(buf);
}

// -- PID math -------------------------------------------------------
float pidCompute(PIDController &pid, float input, float dt) {
  float error = pid.setpoint - input;

  // integral accumulation
  pid.integral += error * dt;

  float pTerm = pid.kp * error;

  // integral term with anti-windup clamp: never let the accumulated
  // integral push the output beyond what the actuator can do.
  float iTerm = pid.ki * pid.integral;
  if (iTerm > pid.outMax) {
    iTerm = pid.outMax;
    if (pid.ki != 0.0f) pid.integral = pid.outMax / pid.ki;
  } else if (iTerm < pid.outMin) {
    iTerm = pid.outMin;
    if (pid.ki != 0.0f) pid.integral = pid.outMin / pid.ki;
  }

  // derivative on measurement (avoids "derivative kick" on setpoint changes)
  float dInput = pid.initialized ? (input - pid.lastInput) / dt : 0.0f;
  float dTerm = -pid.kd * dInput;

  float output = pTerm + iTerm + dTerm;
  output = constrain(output, pid.outMin, pid.outMax);

  pid.lastInput = input;
  pid.initialized = true;

  return output;
}

void pidReset(PIDController &pid, float currentTemp) {
  pid.integral = 0.0f;
  pid.lastInput = currentTemp;
  pid.initialized = true;
}

void updatePIDIfNeeded() {
  if (!pidModeEnabled) return;

  unsigned long now = millis();
  if (now - lastPidRunTime < PID_INTERVAL_MS) return;

  float dt = (lastPidRunTime == 0) ? (PID_INTERVAL_MS / 1000.0f)
                                    : (now - lastPidRunTime) / 1000.0f;
  lastPidRunTime = now;

  float temp = readTMP126();

  if (temp < -40.0f || temp > 150.0f) {
    pidFaultActive = true;
    currentFanDuty = 100;
    setFanDutyCycle(currentFanDuty);
    Serial.println("WARN:PID_TEMP_INVALID");
  } else {
    pidFaultActive = false;
    float output = pidCompute(tempPID, temp, dt);
    currentFanDuty = (uint8_t)lroundf(output);
    setFanDutyCycle(currentFanDuty);
  }

  // Always emit telemetry - even on the fault path - so the host's view
  // of fan duty / fault state never goes stale.
  Serial.print("PID:TEMP:");
  Serial.print(temp, 2);
  Serial.print(",FAN:");
  Serial.print(currentFanDuty);
  Serial.print(",SP:");
  Serial.print(tempPID.setpoint, 2);
  Serial.print(",MODE:");
  Serial.print(pidModeEnabled ? 1 : 0);
  Serial.print(",FAULT:");
  Serial.println(pidFaultActive ? 1 : 0);
}

void setup() {
  Serial.begin(115200);

  unsigned long startWait = millis();
  while (!Serial && (millis() - startWait < 2000)) {
    delay(10);
  }

  Serial.println("SYS:BOOTING...");
  inputString.reserve(30);

  pinMode(ENCODER_A, INPUT_PULLUP);
  pinMode(ENCODER_B, INPUT_PULLUP);
  pinMode(ENCODER_SW, INPUT_PULLUP);

  pinMode(LED_CH1, OUTPUT);
  pinMode(LED_CH2, OUTPUT);
  pinMode(LED_CH3, OUTPUT);
  pinMode(LED_SATURATION, OUTPUT);

  pinMode(TMP126_CS, OUTPUT);
  digitalWrite(TMP126_CS, HIGH);

  SPI.begin();
  init25kHzPWM();

  mcp.begin(0x60);

  lastStateA = digitalRead(ENCODER_A);
  updateLEDs();
  updateDAC();

  Serial.println("SYS:READY");
}

void loop() {
  handleEncoderButton();
  handleEncoderRotation();
  updatePIDIfNeeded();

  while (Serial.available()) {
    char inChar = (char)Serial.read();
    if (inChar == '\n' || inChar == '\r') {
      if (inputString.length() > 0) {
        processSerialCommand(inputString);
        inputString = "";
      }
    } else {
      inputString += inChar;
    }
  }
}

// --- Telemetry Output ---
void transmitSystemState() {
  bool isSaturated = (dacValues[currentChannel] == 0 || dacValues[currentChannel] == 4095);
  Serial.print("CH:");
  Serial.print(currentChannel + 1);
  Serial.print(",VAL:");
  Serial.print(dacValues[currentChannel]);
  Serial.print(",SAT:");
  Serial.print(isSaturated ? "1" : "0");
  Serial.print(",MOCK:");
  Serial.println(mcp.isMockActive() ? "1" : "0");
}

// --- Serial Command Parser ---
void processSerialCommand(String command) {
  command.trim();

  if (command == "ID" || command == "WHOAMI") {
    Serial.print("RSP:ID,");
    Serial.print(DEVICE_TYPE);
    Serial.print(",");
    Serial.print(FW_VERSION);
    Serial.print(",");
    Serial.println(getUniqueID());
  }
  else if (command.startsWith("SET_FAN:")) {
    if (pidModeEnabled) {
      Serial.println("ERR:PID_ACTIVE");
    } else {
      int valueStringIndex = command.indexOf(':');
      int fanValue = command.substring(valueStringIndex + 1).toInt();
      fanValue = constrain(fanValue, 0, 100);
      setFanDutyCycle(fanValue);
      currentFanDuty = fanValue;

      Serial.print("RSP:FAN,");
      Serial.println(fanValue);
    }
  }
  else if (command.startsWith("SET_DAC:")) {
    int colonIndex = command.indexOf(':');
    int commaIndex = command.indexOf(',');

    if (colonIndex != -1 && commaIndex != -1) {
      int targetChannel = command.substring(colonIndex + 1, commaIndex).toInt() - 1;
      int dacValue = command.substring(commaIndex + 1).toInt();

      if (targetChannel >= 0 && targetChannel <= 2) {
        dacValues[targetChannel] = constrain(dacValue, 0, 4095);

        updateDAC();
        checkSaturation();

        Serial.print("RSP:DAC_SET,");
        Serial.print(targetChannel + 1);
        Serial.print(",");
        Serial.println(dacValues[targetChannel]);
      } else {
        Serial.println("ERR:INVALID_CH");
      }
    } else {
      Serial.println("ERR:INVALID_FORMAT");
    }
  }
  else if (command == "GET_DAC") {
    Serial.print("RSP:DAC_VALS,");
    Serial.print(dacValues[0]);
    Serial.print(",");
    Serial.print(dacValues[1]);
    Serial.print(",");
    Serial.println(dacValues[2]);
  }
  else if (command == "GET_TEMP") {
    float temperature = readTMP126();
    Serial.print("RSP:TMP,");
    Serial.println(temperature, 2);
  }
  else if (command.startsWith("SET_PID_MODE:")) {
    int idx = command.indexOf(':');
    int mode = command.substring(idx + 1).toInt();
    pidModeEnabled = (mode != 0);
    pidFaultActive = false;   // <-- added: clear stale fault state on any mode change

    if (pidModeEnabled) {
      float currentTemp = readTMP126();
      pidReset(tempPID, currentTemp);
      lastPidRunTime = 0;
    } else {
      currentFanDuty = 0;
      setFanDutyCycle(0);
    }

    Serial.print("RSP:PID_MODE,");
    Serial.println(pidModeEnabled ? 1 : 0);
  }
  else if (command.startsWith("SET_PID_SETPOINT:")) {
    int idx = command.indexOf(':');
    float sp = command.substring(idx + 1).toFloat();
    tempPID.setpoint = sp;

    Serial.print("RSP:PID_SETPOINT,");
    Serial.println(tempPID.setpoint, 2);
  }
  else if (command.startsWith("SET_PID_GAINS:")) {
    int idx = command.indexOf(':');
    String rest = command.substring(idx + 1);
    int c1 = rest.indexOf(',');
    int c2 = rest.indexOf(',', c1 + 1);

    if (c1 != -1 && c2 != -1) {
      tempPID.kp = rest.substring(0, c1).toFloat();
      tempPID.ki = rest.substring(c1 + 1, c2).toFloat();
      tempPID.kd = rest.substring(c2 + 1).toFloat();

      Serial.print("RSP:PID_GAINS,");
      Serial.print(tempPID.kp, 3);
      Serial.print(",");
      Serial.print(tempPID.ki, 3);
      Serial.print(",");
      Serial.println(tempPID.kd, 3);
    } else {
      Serial.println("ERR:INVALID_FORMAT");
    }
  }
  else if (command == "GET_PID") {
    Serial.print("RSP:PID_STATE,");
    Serial.print(pidModeEnabled ? 1 : 0);
    Serial.print(",");
    Serial.print(tempPID.setpoint, 2);
    Serial.print(",");
    Serial.print(tempPID.kp, 3);
    Serial.print(",");
    Serial.print(tempPID.ki, 3);
    Serial.print(",");
    Serial.print(tempPID.kd, 3);
    Serial.print(",");
    Serial.print(currentFanDuty);
    Serial.print(",");
    Serial.print(readTMP126(), 2);
    Serial.print(",");
    Serial.println(pidFaultActive ? 1 : 0);
  }
  else {
    Serial.println("ERR:CMD");
  }
}

float readTMP126() {
  SPI.beginTransaction(SPISettings(10000000, MSBFIRST, SPI_MODE0));
  digitalWrite(TMP126_CS, LOW);
  uint8_t msb = SPI.transfer(0x00);
  uint8_t lsb = SPI.transfer(0x00);
  digitalWrite(TMP126_CS, HIGH);
  SPI.endTransaction();

  int16_t rawData = (msb << 8) | lsb;
  return (rawData >> 2) * 0.03125;
}

// --- UI & Peripheral Control Logic ---
void handleEncoderButton() {
  bool reading = digitalRead(ENCODER_SW);

  if (reading != lastButtonReading) {
    lastDebounceTime = millis();
  }

  if ((millis() - lastDebounceTime) > debounceDelay) {
    if (reading != debouncedButtonState) {
      debouncedButtonState = reading;

      if (debouncedButtonState == LOW) {
        currentChannel++;
        if (currentChannel > 2) currentChannel = 0;

        updateLEDs();

        #if DEBUG_MODE
          transmitSystemState();
        #endif
      }
    }
  }

  lastButtonReading = reading;
}

void handleEncoderRotation() {
  int currentStateA = digitalRead(ENCODER_A);
  if (currentStateA != lastStateA && currentStateA == LOW) {
    if (digitalRead(ENCODER_B) == currentStateA) {
      if (dacValues[currentChannel] < 4045) dacValues[currentChannel] += 50;
      else dacValues[currentChannel] = 4095;
    } else {
      if (dacValues[currentChannel] > 50) dacValues[currentChannel] -= 50;
      else dacValues[currentChannel] = 0;
    }

    updateDAC();
    checkSaturation();

    #if DEBUG_MODE
      transmitSystemState();
    #endif
  }
  lastStateA = currentStateA;
}

void updateLEDs() {
  digitalWrite(LED_CH1, currentChannel == 0 ? HIGH : LOW);
  digitalWrite(LED_CH2, currentChannel == 1 ? HIGH : LOW);
  digitalWrite(LED_CH3, currentChannel == 2 ? HIGH : LOW);
  checkSaturation();
}

void updateDAC() {
  mcp.setChannelValue(MCP4728_CHANNEL_A, dacValues[0]);
  mcp.setChannelValue(MCP4728_CHANNEL_B, dacValues[1]);
  mcp.setChannelValue(MCP4728_CHANNEL_C, dacValues[2]);
}

void checkSaturation() {
  if (dacValues[currentChannel] == 0 || dacValues[currentChannel] == 4095) {
    digitalWrite(LED_SATURATION, HIGH);
  } else {
    digitalWrite(LED_SATURATION, LOW);
  }
}

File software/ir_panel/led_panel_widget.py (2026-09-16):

"""
qtpy widget for the Arduino LED Panel Controller.

All serial I/O happens on a background QThread (PanelWorker); discovery
also runs on its own QThread (PortScanner). A pyqtgraph-based live plot
tracks temperature, setpoint, and fan duty cycle over time.
"""

from __future__ import annotations

import os
import queue
import sys
import time
from collections import deque
from typing import List, Optional

# --- Qt binding setup -------------------------------------------------
import qtpy
from qtpy.QtCore import QThread, Signal, Qt
from qtpy.QtWidgets import (
    QApplication,
    QCheckBox,
    QComboBox,
    QDoubleSpinBox,
    QFormLayout,
    QGroupBox,
    QHBoxLayout,
    QLabel,
    QMessageBox,
    QPushButton,
    QScrollArea,
    QSplitter,
    QSpinBox,
    QVBoxLayout,
    QWidget,
)

# pyqtgraph does its own Qt-binding detection, independent of qtpy. If it
# picks a *different* binding than qtpy did (e.g. PyQt5 vs PySide6), both
# get loaded into the same process and things crash in unpredictable ways.
# Force pyqtgraph to use whatever binding qtpy already resolved.
_QTPY_TO_PYQTGRAPH = {
    "pyqt5": "PyQt5",
    "pyside2": "PySide2",
    "pyqt6": "PyQt6",
    "pyside6": "PySide6",
    "pyqt": "PyQt4",
    "pyside": "PySide",
}
os.environ.setdefault(
    "PYQTGRAPH_QT_LIB", _QTPY_TO_PYQTGRAPH.get(qtpy.API_NAME.lower(), "PyQt5")
)

import pyqtgraph as pg  # noqa: E402  (must come after the env var is set)

from led_panel import (
    LEDPanelError,
    LEDPanelInfo,
    PIDState,
    SerialLEDPanel,
)


# ============================================================== #
# Background worker: scans ports using the ID handshake
# ============================================================== #
class PortScanner(QThread):
    finished_scan = Signal(list)  # List[LEDPanelInfo]

    def run(self):
        try:
            panels = SerialLEDPanel.list_available_panels()
        except Exception:
            panels = []
        self.finished_scan.emit(panels)


# ============================================================== #
# Background worker: owns the serial connection to one board
# ============================================================== #
class PanelWorker(QThread):
    connection_changed = Signal(bool)
    error_occurred = Signal(str)

    dac_value_changed = Signal(int, int)      # channel, value
    dac_values_loaded = Signal(list)          # [v0, v1, v2]
    fan_changed = Signal(int)
    temperature_changed = Signal(float)
    telemetry_received = Signal(dict)

    pid_mode_changed = Signal(bool)
    pid_setpoint_changed = Signal(float)
    pid_gains_changed = Signal(float, float, float)
    pid_state_loaded = Signal(object)         # PIDState
    pid_telemetry_received = Signal(dict)

    log_message = Signal(str)

    def __init__(self, panel: SerialLEDPanel, poll_interval: float = 2.0):
        super().__init__()
        self.panel = panel
        self.poll_interval = poll_interval
        self._jobs: "queue.Queue" = queue.Queue()
        self._running = False

    # -- lifecycle ------------------------------------------------- #
    def run(self):
        self._running = True
        self.panel.set_telemetry_callback(lambda d: self.telemetry_received.emit(d))
        self.panel.set_pid_telemetry_callback(lambda d: self.pid_telemetry_received.emit(d))
        self.panel.set_log_callback(lambda s: self.log_message.emit(s))

        try:
            self.panel.connect()
        except LEDPanelError as e:
            self.error_occurred.emit(str(e))
            self.connection_changed.emit(False)
            return

        self.connection_changed.emit(True)
        last_poll = 0.0

        while self._running:
            try:
                func = self._jobs.get(timeout=0.1)
                try:
                    func()
                except LEDPanelError as e:
                    self.error_occurred.emit(str(e))
            except queue.Empty:
                pass

            now = time.monotonic()
            if now - last_poll >= self.poll_interval:
                last_poll = now
                try:
                    temp = self.panel.get_temperature_degC()
                    self.temperature_changed.emit(temp)
                except LEDPanelError as e:
                    self.error_occurred.emit(str(e))

        self.panel.disconnect()
        self.connection_changed.emit(False)

    def stop(self):
        self._running = False
        self.wait(3000)

    # -- job submission API (call from the GUI thread) ------------- #
    def _submit(self, func):
        self._jobs.put(func)

    def request_set_dac(self, channel: int, value: int):
        def _job():
            val = self.panel.set_dac_raw(channel, value)
            self.dac_value_changed.emit(channel, val)
        self._submit(_job)

    def request_set_fan(self, percent: int):
        def _job():
            val = self.panel.set_fan_percent(percent)
            self.fan_changed.emit(val)
        self._submit(_job)

    def request_get_dac_values(self):
        def _job():
            vals = self.panel.get_dac_values()
            self.dac_values_loaded.emit(vals)
        self._submit(_job)

    # -- PID job submission ----------------------------------------- #
    def request_set_pid_mode(self, enabled: bool):
        def _job():
            val = self.panel.set_pid_mode(enabled)
            self.pid_mode_changed.emit(val)
        self._submit(_job)

    def request_set_pid_setpoint(self, setpoint_degC: float):
        def _job():
            val = self.panel.set_pid_setpoint(setpoint_degC)
            self.pid_setpoint_changed.emit(val)
        self._submit(_job)

    def request_set_pid_gains(self, kp: float, ki: float, kd: float):
        def _job():
            vals = self.panel.set_pid_gains(kp, ki, kd)
            self.pid_gains_changed.emit(*vals)
        self._submit(_job)

    def request_get_pid_state(self):
        def _job():
            state = self.panel.get_pid_state()
            self.pid_state_loaded.emit(state)
        self._submit(_job)
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

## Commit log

2026-06-11 adding files
    [control.kicad_pcb, control.kicad_sch, panel_0.kicad_pcb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]
2026-06-11 changed folder name
    [control.kicad_pcb, control.kicad_sch, panel_0.kicad_pcb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]
2026-06-11 25kHz pwm for fan ctrl
2026-06-11 comments timer
2026-06-12 add spi temp board and connector
    [panel_0.kicad_pcb, panel_0.kicad_sch]
2026-06-12 removing old thermocouple ic
    [control.kicad_sch]
2026-06-12 external spi temp chip
    [control.kicad_pcb, control.kicad_sch]
2026-06-12 added alert pullup
    [control.kicad_pcb, control.kicad_sch]
2026-06-12 added extra mounting points
    [panel_0.kicad_pcb, panel_0.kicad_sch]
2026-06-12 rework pcb layout
    [control.kicad_pcb, control.kicad_sch]
2026-06-15 removing 90deg turns
    [control.kicad_pcb]
2026-06-15 silkscreen r1
    [control.kicad_pcb]
2026-06-15 cleaning traces
    [control.kicad_pcb]
2026-06-15 changed molex connector
    [control.kicad_pcb, control.kicad_sch]
2026-07-16 add folder and correct typo
    [ir_panel.ino]
2026-07-16 added schottky diode to 12V
    [control.kicad_pcb]
2026-07-16 fixed diode
    [control.kicad_pcb, control.kicad_sch]
2026-07-16 removed diode
2026-07-21 updated connectors and connector position
    [control.kicad_pcb, control.kicad_sch]
2026-09-16 add BOMs
    [BOM.csv, control.csv, panel_0.csv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]
2026-09-16 completing driver and adding widget
2026-09-16 keyboard tracking false and PWM range 0-99
2026-09-16 meanwell psu
    [BOM.csv]
2026-09-16 adding PID temperature control
2026-09-17 weird char
    [BOM.csv]
2026-09-17 fix the mess
    [control.FCStd]
2026-09-17 fix model
    [control-base.stl, control-lid.stl, control.FCStd]
2026-09-17 adding fuses
    [BOM.csv]
2026-09-22 add opening for usb
    [control-lid.stl, control.FCStd]
2026-09-24 center the knob
    [rotary_encoder.kicad_pcb]
2026-09-24 breakout case
    [breakout-base.stl, breakout-panel.stl, breakout.FCStd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]
2026-09-24 holes in the base
    [breakout-base.stl, breakout.FCStd]
